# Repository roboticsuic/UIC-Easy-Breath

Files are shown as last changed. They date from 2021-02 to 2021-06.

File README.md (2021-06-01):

# Bioengineered breathing assistant for COVID-19

We are a group of four girls, form UIC, trying to mimic a mechanical ventilator for COVID-19 patients.
The overall mechanism consists in a 3D printed breathing machine structure connected to several electrical devices and all derived from an Arduino MKR 1000. There is a video of the all project in _EXTRA_ folder.

Here you will find both the 3D files in order to print the structure, and also the specific code to control it.
Remember that we are a group of undergraduates students, so this project is educational.

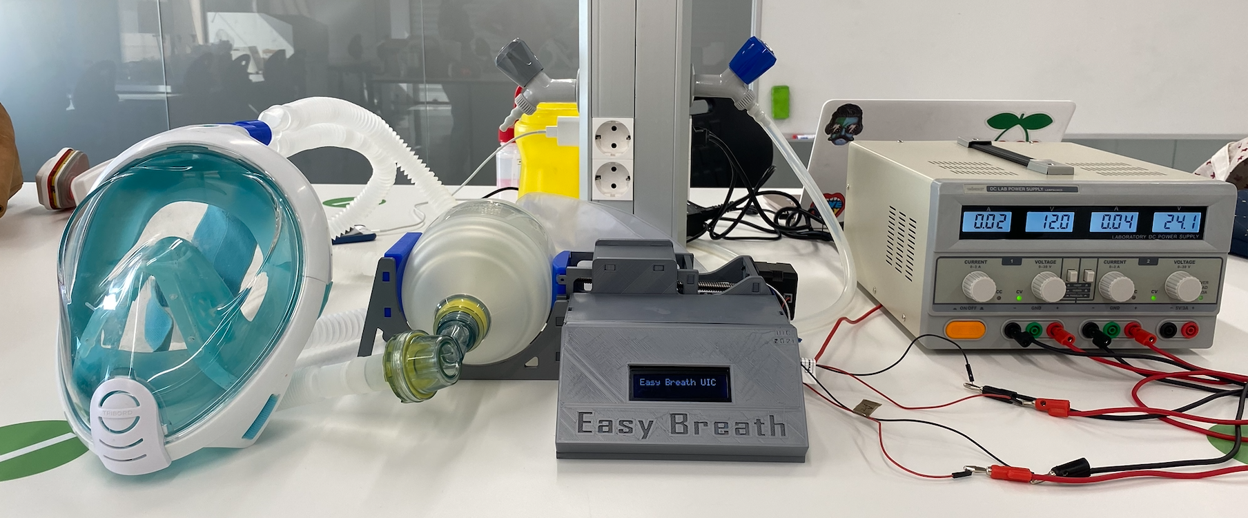
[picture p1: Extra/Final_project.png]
Final_project
 

**To contact us:**

Laura Olariaga: lolariaga@uic.es.

Ana Gatius: gatiusana@uic.es.

Èlia Vendrell: eliavendrell@uic.es.

Meritxell Clos: meritxell.clos@uic.es.

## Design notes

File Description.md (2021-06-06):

# UIC Easy Breath
## PROJECT: **Bioengineered breathing assistant for COVID-19**

At the end of 2019 a global pandemic changed our lives: we weren’t able to leave home, couldn’t hang out with friends… What is more, the medical services collapsed due to the big necessity of medical attention for COVID patients.

This project is based on the manufacture of a breathing assistant for COVID-19, a device designed to help those suffering severe breathing difficulties while affected by this virus. The aim of this project is to report how we created an electric device with the ability to provide sufficient oxygen to those patients.

The overall mechanism consists in a 3D printed breathing machine structure connected to several electrical devices and all derived from an Arduino MKR 1000.

The project is developed on the basis of a previous project that we found in Thingiverse (https://www.thingiverse.com/thing:4255247), where we got the breathing assistant model that we decided to print in 3D. In addition, we modified some of the previous pieces and also printed extra ones. For instance,  a display adapted box to place all the electronics of the mechanism

**_1. Objectives:_**

- Learn the basics of 3D printing and electronics in order to create a bioengineered breathing assistant for COVID-19.
- Create an accessible and fast 3D printed device in order to cover the urgent necessities during the COVID pandemic.
- Use motors and electronic devices in order to understand its functions.
- Be able to generate an Arduino code able to mimic the movements of the preexisting breathing machines, with the corresponding sensor.

**_2. Materials:_**

- For 3D printing: 
   - Blue, white and grey PLA.

- Softwares:
   - _SolidWorks_, to create and modify pieces.
   - _Ultimaker Cura_, to adjust setting parameters of the 3D printer.
   - _Meshmixer_, to detail and modify already created pieces.
   - _Prusa Slicer_, to add supports to the pieces before printing.

- For the electronics of the breathing assistant:
   - Arduino MKR1000.
   - Stepper motor NEMA 17.
   - Spindle Igus step 25.
   - Screw spindle Igus step 25.
   - Driver TB6600.
   - Screen SparkFun SerLCD.
   - Energy source 24V (5A).
   - Power regulator step down (24V to 10V).
   - Mechanical limit switch.
   - Pressure sensor (001PG2A5).
   - Buzzer.
   - Voltage conversor.
   - Voltage source (2 outcomes).

 - For the respiratory circuit:
   - Ambu respiratory bag.
   - Two corrugated tubes.
   - APL valve.
   - Peep valve.
   - Directionality valves.
   - Filter.

**_3. Definitions_:**

**MKR 1000 WIFI**:
- Price: 26.50€ 
- Size: Length 61.5mm Width 25mm.
- Weight: 32gr.
- Microcontroller: SAMD21 Cortex-MO + 32bit low power ARM MCU.
- Board Power Supply (USB/VIN): 5V.
- Supported Battery: Li-Po single cell, 3.7V, 700mAh minimum.
- Circuit Operating Voltage: 3.3V
- Digital I/O Pins: 8.
- PWM Pins: 12 (0,1,2,3,4,5,6,7,8,10,A3 -or 18 -, A4 -or 19).
- UART: 1.
- SPI: 1.
- 12C: 1.
- Analog Input Pins: 7 (ADC 8/10/12 bit).
- Analog Output Pins: 1(DAC 10 bit).
- External Interrupts: 8(0,1,4,5,6,7,8,A1 -or 16-, A2 - or 17).
- DC current per I/O Pin: 7mA.
- Flash Memory: 256KB.
- SRAM: 32KB.
- EEPROM: no.
- Clock Speed: 32.768kHz (RTC), 48MHz.
- LED_BUILTIN: 6.
- Full-speed USB Device and embedded Host.
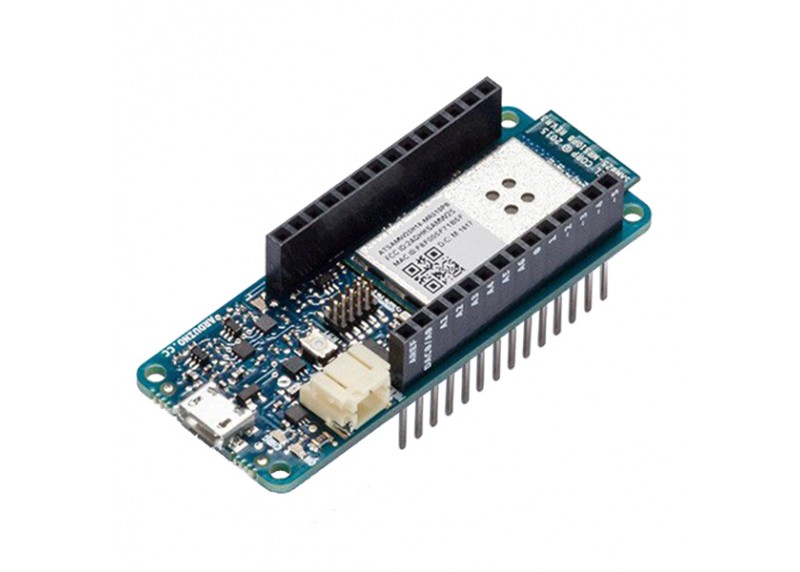
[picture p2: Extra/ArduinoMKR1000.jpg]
ArduinoMKR1000
 

**Pressure Sensor**:
- Price: 16,08€
- Manufactures: Honeywell.
- Model: 001PG2A5.
- Output Type: I2C, Address 0x28.
- Supply Voltage:  5.0 Vdc.
- Use: Medical Ventilators.
- Pressure Range: 0 psi to 1 psi.
- Pressure: Gauge.
- Weight: 4,250 g.
- Max. tension: 5,25V.
- Min. tension: 4,75V.
- Pinouts: Check table below.
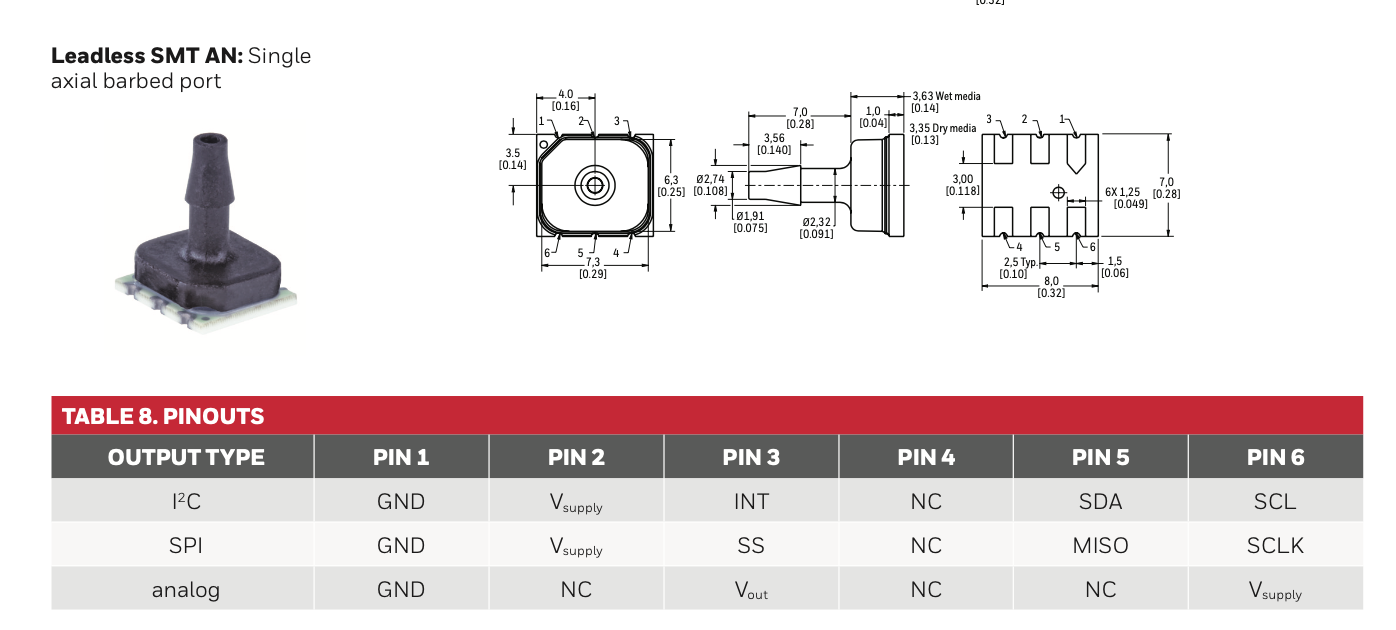
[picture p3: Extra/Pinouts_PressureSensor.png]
Pinouts_PressureSensor
- 

**Screen SparkFun SerLCD**
- Price: 16,37€.
- Dimensions: 16x2mm, RGB on Black Display.
- Manufactures: SparkFun.
- InPut Voltage: 3.3V.
- Weight: 2.2084 g.
- Connection: Qwiic.

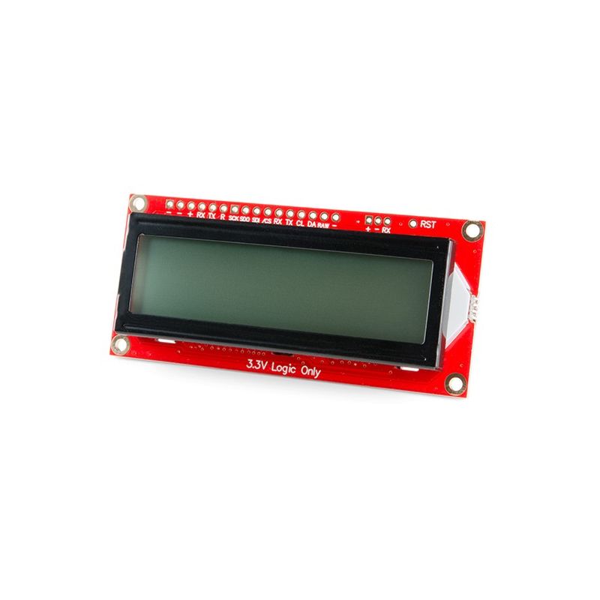
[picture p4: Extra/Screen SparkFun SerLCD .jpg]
Screen%20SparkFun%20SerLCD%20%20


**Stepper motor NEMA 17**
- Price: 21,66€.
- Size: 42.3x48mm, without including the axis.
- Weight: 350 g.
- Axis diameter: 5mm.
- Axis length: 25mm.
- Steps per turn: 200 (1.8º/step.
- Current: 1.2 Amps per winding.
- Voltage: 4V.
- Resistance: 3.3 Ohm per bobbin.
 
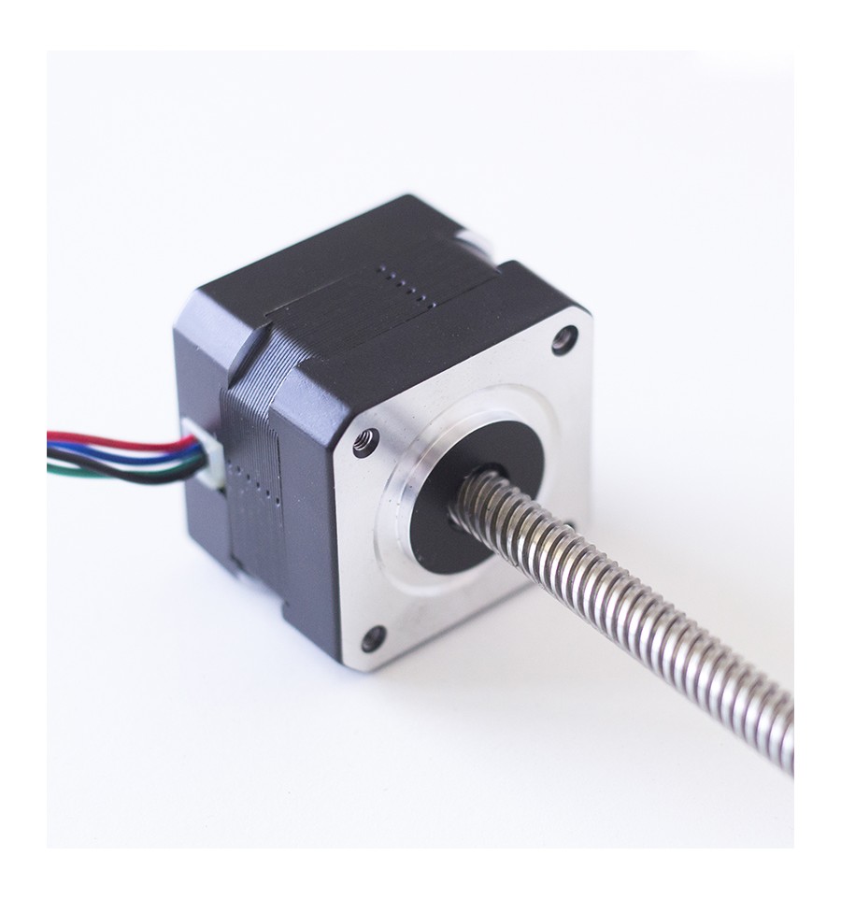
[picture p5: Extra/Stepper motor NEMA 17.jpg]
Stepper%20motor%20NEMA%2017


**Driver TB6600**
- Price: 18.90€.
- Input current: 0-5.0 A.
- Output current: 0.5 - 4A.
- Power: 160W
- Temperature: -10 to 45 degrees.
- Weight: 200g.
- Dimensions: 96x56x33mm.
- Connections: See picture above.

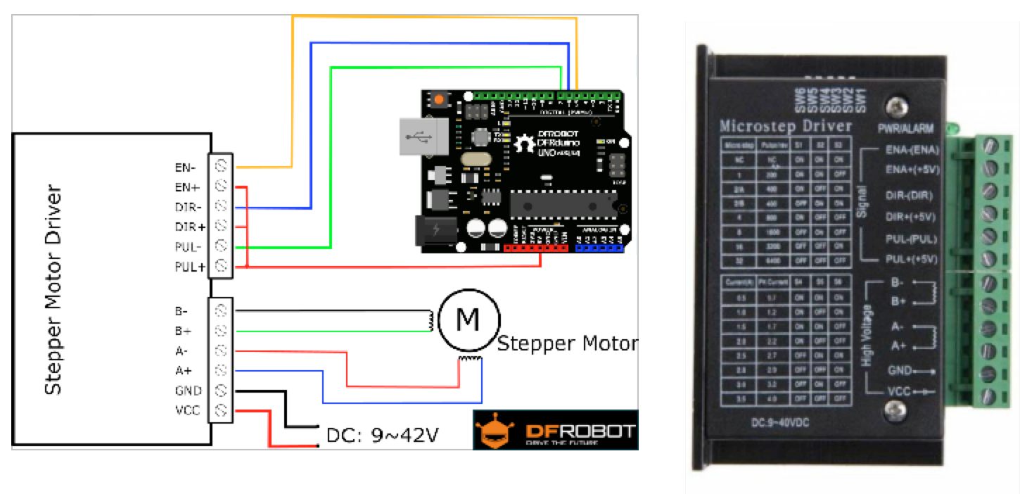
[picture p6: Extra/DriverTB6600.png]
DriverTB6600


**XL4015 DC Voltage Converter**
- Price: 3€.
- Input Voltage: 4.5V - 38V.
- OutPut Volatge: 1.25 - 36.5V
- OutPut power: 75W.
- Current Voltage: 4,5A.
- Temperature: -40 to 85 degrees.
- Operating frequency: 180kHz.
- Dimensions: 62x38x15 mm.
- Short circuit protection: Yes
- Functions: Step-down converter with overcurrent protection.
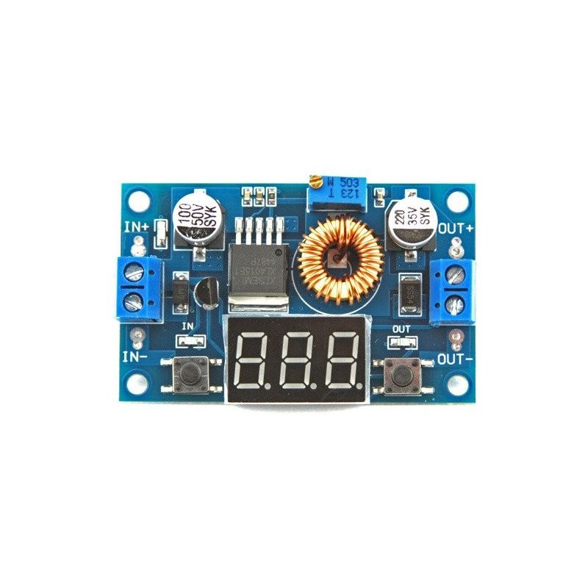
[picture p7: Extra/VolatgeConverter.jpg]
VolatgeConverter


**_4. Circuit_:**

Here you will find the proposed circuit with the corresponding connections:
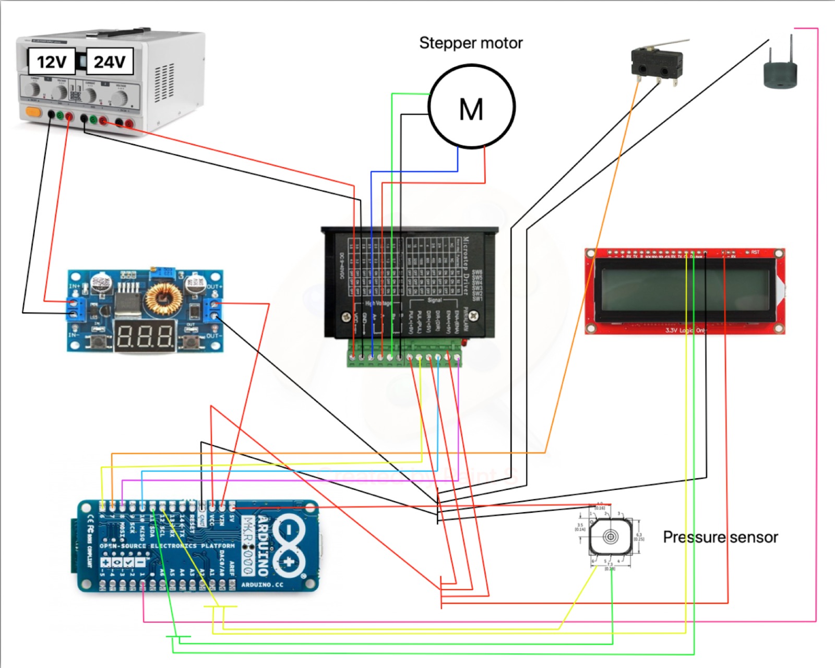
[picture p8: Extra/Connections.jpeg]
Connections


**Pressure sensor**

_See picture in definitions section._
- 3.3V corresponds to 5V
- SDA and SCL are connected to arduino
- The two remaining pins are not used

**XL4015 DC Voltage Converter**

_See picture in definitions section._ 
- IN+/- connected to voltage source 12V
- OUT+ connected to VIN arduino MK1000
- OUT- connected to GND arduino MK1000

**Driver TB6600 and Stepper motor NEMA 17**

_See picture in definitions section._   
- ENA- pin 8
- ENA+, DIR+, PULL+ → 3.3V 
- DIR- pin 10
- PULL- pin 6
- B- (black), B+ (green), A- (red), A+ (blue) → stepper motor
- GND, Vcc → voltage source 24V 

**Screen SparkFun SerLCD**
   
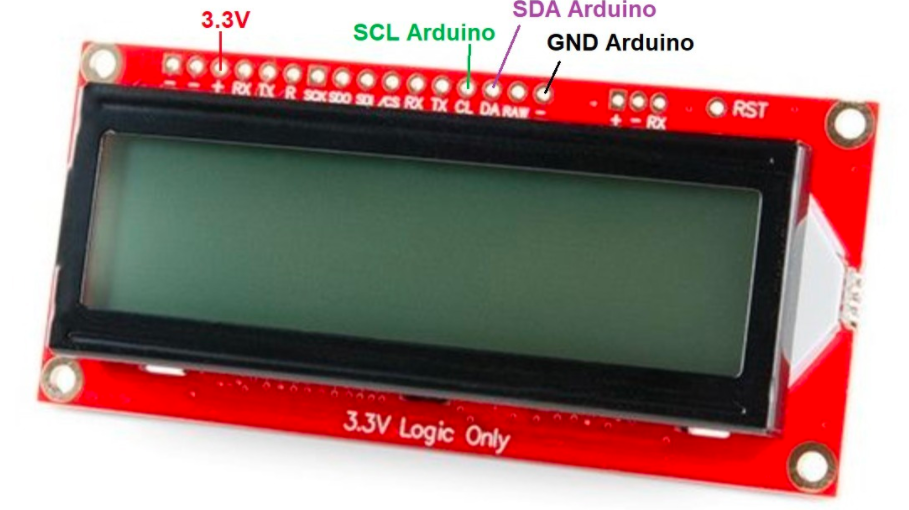
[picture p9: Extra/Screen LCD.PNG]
Screen%20LCD


**Buzzer** 
   
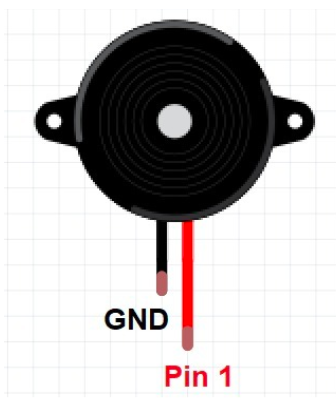
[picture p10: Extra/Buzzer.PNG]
Buzzer


**Limit Switch**
   
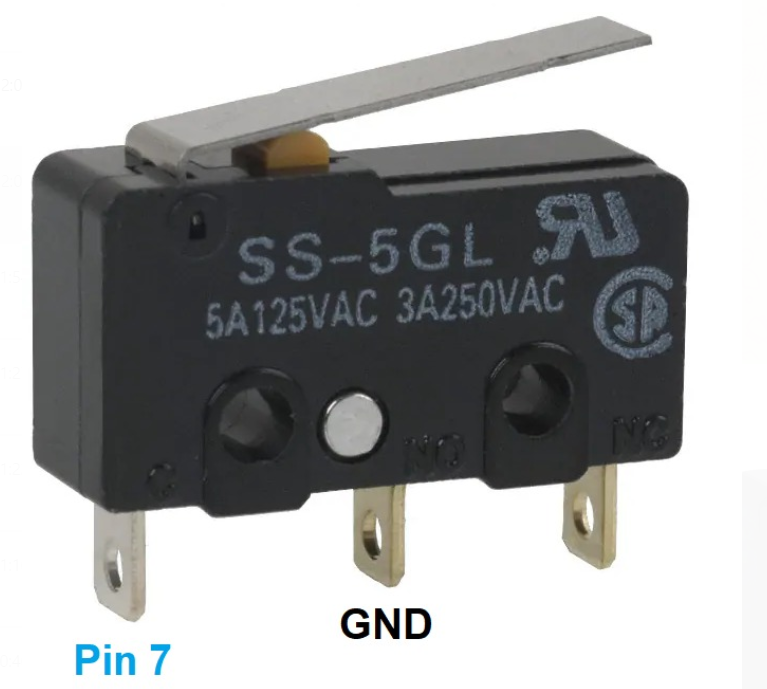
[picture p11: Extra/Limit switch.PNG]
Limit%20switch


_Notes:_
We have used common conexions for several components which end up in the same pin.
- A common conexion for SDA and SLA for the pressure sensor and the screen in arduino pins.
- OUT- from the voltage conversor is connected to GND arduino, while GND connections in the pressure sensor, buzzer, limit switch and screen are commonly connected to the first one.
- Vcc pin from arduino is commonly connected to ENA+, DIR+, PULL+ and 3.3V pin from screen.

**_5. Code_:**
   
Here you will find the main explanation of our code. The entire code is in the _CODE_ folder.

_Libraries:_  
   - Wire: Communicates with the IC2.
   - SerLCD: Communicates with the screen.
   - Honeywell_ABP: Communicates with the pressure sensor.

_Medical calculations:_
   - Used to modulate the respirator depending on the patient’s needs.

_Communications with Monitor Serie:_     
   - Serial.begin(9600)→ 9600ms are the velocity that the massage is send to the Monitor Serie.
   - Serial.setTimeout(100)→ 100ms are the waiting time to print in the screen.

_Define Inputs&Output:_
  - pinMode(finalcarrera, INPUT_PULLUP)→ Pullup as monitor the state of a switch.
  - Scl→ Is the system clock.
  - Sda→ Is the system data.

_Screen communications with the Monitor Serie:_
   - Used for:
      - Displacement
      - Breathing per minute (rpm)
         - Total breathing counting; as is an integer, its limit is 32 bits or 2.147.483.647 rpm.
      - Ratio inhalation/expiration 

_Calculations during process:_
   - Inhalation_
      - digitalWrite(dirNeg, HIGH)→ High as the movement is in X negative.
   - Expiration:
      - digitalWrite(dirNeg, LOW)→ Low as the movement is in X positive.
            
_Limit switch and Buzzer:_
   - Used for:
       - If low:
          - It will show an error, as the machine is obstructed and isn’t working.
          - When an error, the buzzer sounds.
       - If high:
          - Is for the expiration movements.
          - When the limit switch is high, it means that the motor has reach the maximal position, and it turns to the other direction (X negative)

_Pressure Sensor:_
   - Used for:
       - If no extra pressure: the sensor is working but without reporting the information on the screen.
       - If too much pressure: the sensor detects this increase. Without stopping the ventilator, there are some modifications:
          - The screen reports the number in cmH2O.
          - The buzzer sounds for 1 second.
    
_Reset:_
   - Used to reset the program when necessary, restarting it again at the introduction of new variables.

**_6. Softwares_:**

**SolidWorks**

 _SolidWorks_ is modeling a computer-aided design (CAD) program that allowed us to create the breath assistant's structure quickly and precisely. The whole structure is composed of 12 different pieces and all of them have to fit with each other, as this project doesn’t contain any screws or ties. However, this part didn’t require a lot of time as all the 12 pieces were previously created by another Catalan University (UPC). A maximum of five days were required for printing the whole structure. The final outcome was the following: 
 
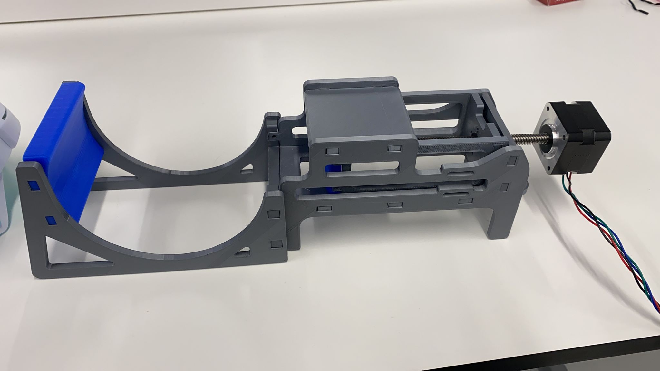
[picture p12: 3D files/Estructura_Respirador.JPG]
Estructura_Respirador
 

On the other hand, _SolidWorks_ was constantly used during our project due to the improvements that our group decided to do. To do that, we used the _SolidWorks_ program to create a new plane in the upper surface, and insert the corresponding text. The difficult part was to figure out which direction was the perfect one, due to the face-mask connector would be seen in the opposite direction. On the other hand, we also incorporare our logo in the frontal part of the box and our surnames in the lateral part of it.
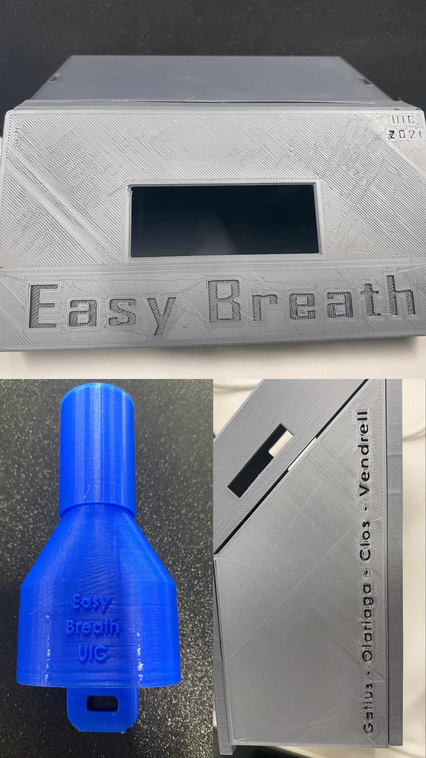
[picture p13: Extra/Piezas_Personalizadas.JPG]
Piezas_Personalizadas


Secondly, this program was also used to create the needed structure to connect the breath assistant with the medical tubs. To do it, we measured the most external part of both devices with a vernier caliper, and with such dimensions, we created the connector.
Thirdly, we decided that one of the initial 12 structures had to have all its surface with PLA. To do that, we create a new plan over the created, and we extrude it. 

Finally, we wanted to create a box to keep all the tools together and well-organized. But this box couldn’t be as the typical ones, but with a certain orientation in one of the faces as we also have a screen to fit inside of it. Therefore, the box had to be composed of different parts. First, we had to modify a preexisting project piece so the box could be attached to the breath machine. Secondly, the back part was created and also the laterals. Finally, the screen face  was designed with all the modifications needed to be able to use all buttons. As can be seen in the image below, all parts have rectangle holes or rectangular extrusions so they can be ansamble together and form the desired box.
In order to know if the box was designed properly, we assembled all the new pieces with Solid works, and the result is the following image.  
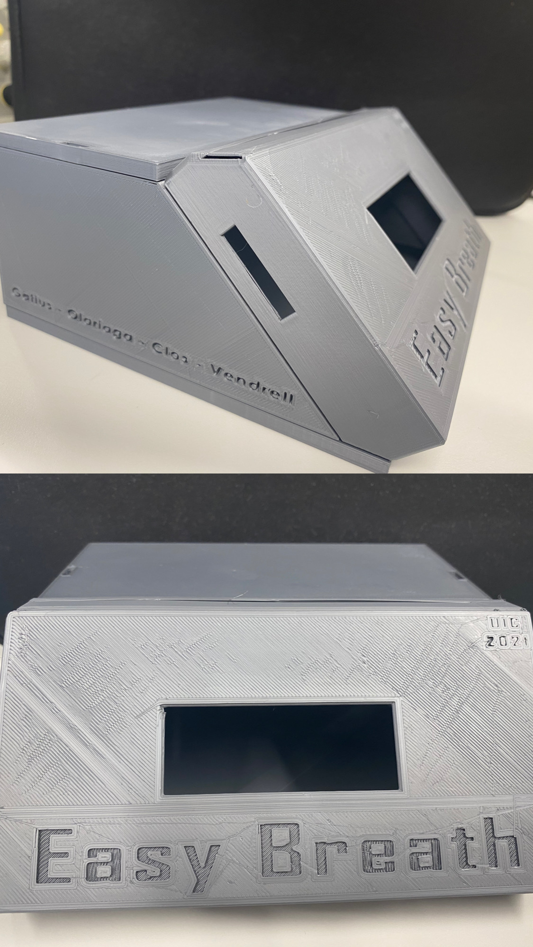
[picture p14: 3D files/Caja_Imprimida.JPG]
Caja_Imprimida


**Meshmixer**

_Meshmixer_ is a free software able to modify files in order to work with triangle meshes. We used it with the purpose of decreasing the adaptor’s resolution. This was due to the need to modify the structure to connect the tubes of the vent system. Moreover, we delete the preexisting letters on its surface to put on our own.

**Ultimaker Cura**

_Ultimaker Cura_ is a cutting software, which converts 3D models into G-code files, which will provide the 3D printer with all the necessary instructions for printing. It converts files in STL format to physical parts. All figures have been converted with Ultimaker Cura before printing. We adapt the printing parameters to improve the PLA printing.    

**Prusa Slicer**

_Prusa Slicer_, is a cutting software, which converts 3D models into G-code files, which will provide the 3D printer with all the necessary instructions for printing. We also used this software to print the adaptor but with the correct support in order to be printed accurately. See picture below.

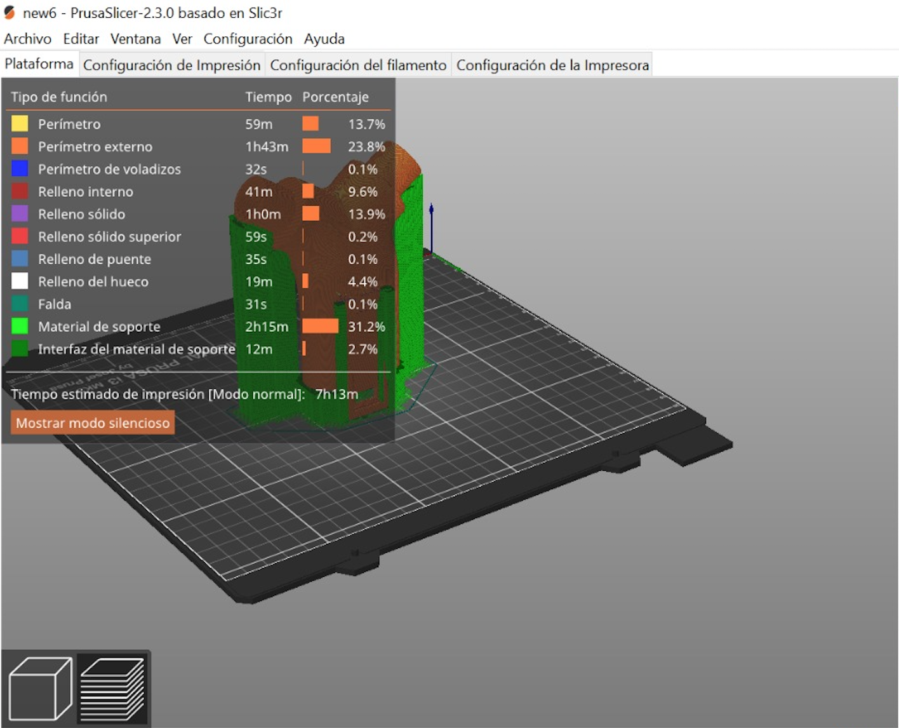
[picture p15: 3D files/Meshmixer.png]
Meshmixer


**_7. Conclusions_:**

Once our final project is done, we can conclude the following statemnts:

The aim of the project was to create a mechanical ventilator that worked automatically and was able to surpass common errors without the help of a medical assistant. The structural parts were printed with a MK3 PRUSA 3D printer with PLA in blue and grey colors. The box that holds all the electronics is composed of five parts that bind together by holes and extrusions, has a hole for the cables to pass, and has the Easy Breath logo in the front. The Arduino used was the MKR1000 model that combines the switch, sensor pressure, I2C screen, driver, buzzer, voltage converter, and stepper motor. The whole structure is connected to a 24V and 12V power supply. Errors that the program described can solve include: the detection of an increase of pressure of over 10 cmH2O that it showed in the screen visually and by a sound by the buzzer, and the detection of an early click of the switch button before it is necessary, the buzzer will also make a sound.

The project holds all the objectives proposed from the beginning, solving other issues found during the process being so; the mechanical ventilator can be printed with a conventional printer machine, Arduino is a proper device to control heavy files and structured document helps to improve existents projects. The last one being the most important one, it is essential for a public finished project to show and be well documented having not only the datasheet but also the exact device models. As so, we have described and attached all the files we have used so the project can be reproduced step by step.

As for future changes and improvements, a reset function can be included in the code. The reset function is useful in extreme cases when an external object gets attached to the device, for instance. If a cable or object gets stuck in the route of the stepper motor movement, there is a need of restarting the code without disconnecting the device. In the project, this approach was solved by showing an error message in the screen or showing the pressure, as well as a warning buzzer, and continuing the loop without stopping. Another alternative to polishing the project is to add a more complex screen that has buttons to select or is tactile, this is so a laptop is no needed.

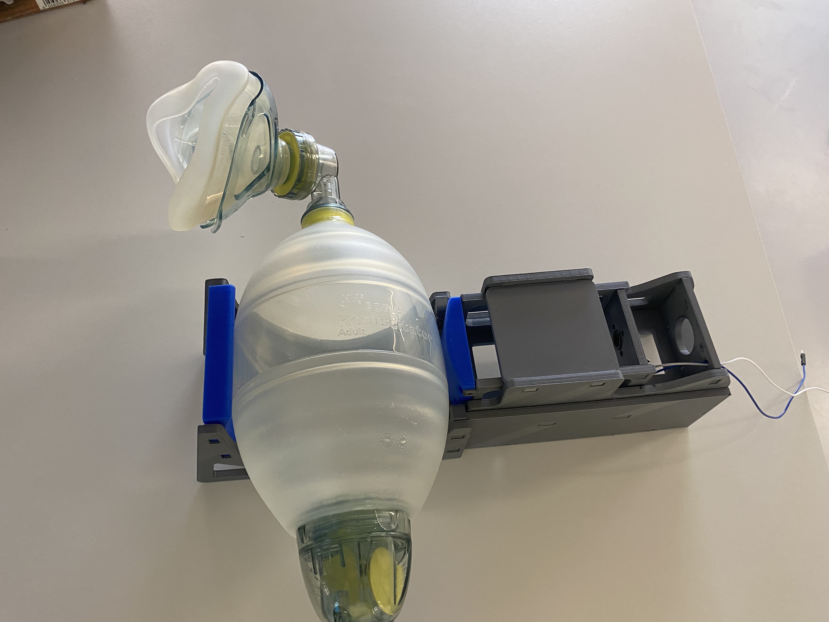
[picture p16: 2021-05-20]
Extra/Structure.JPG

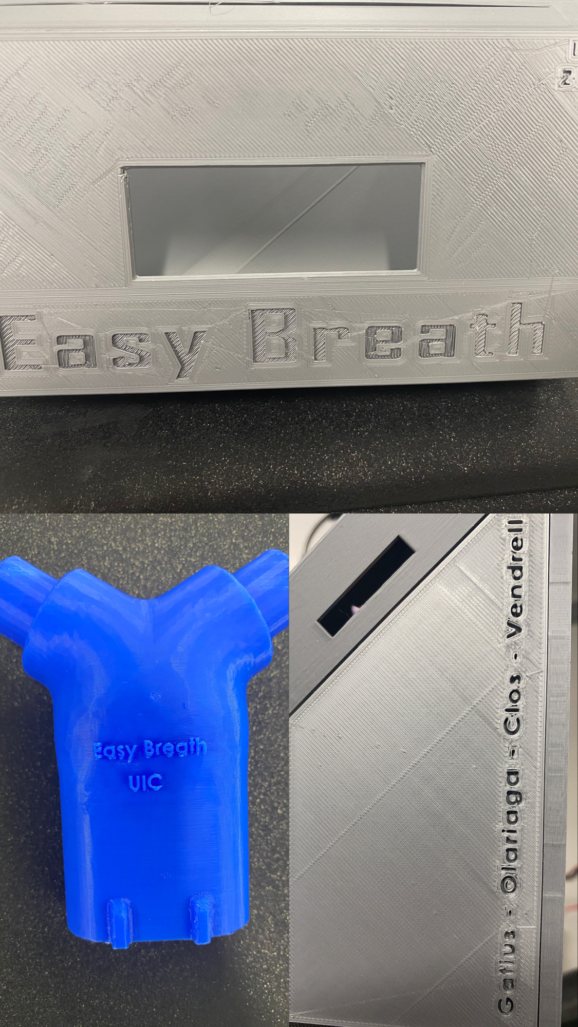
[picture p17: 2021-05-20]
3D files/Piezas_Personalizadas.JPG

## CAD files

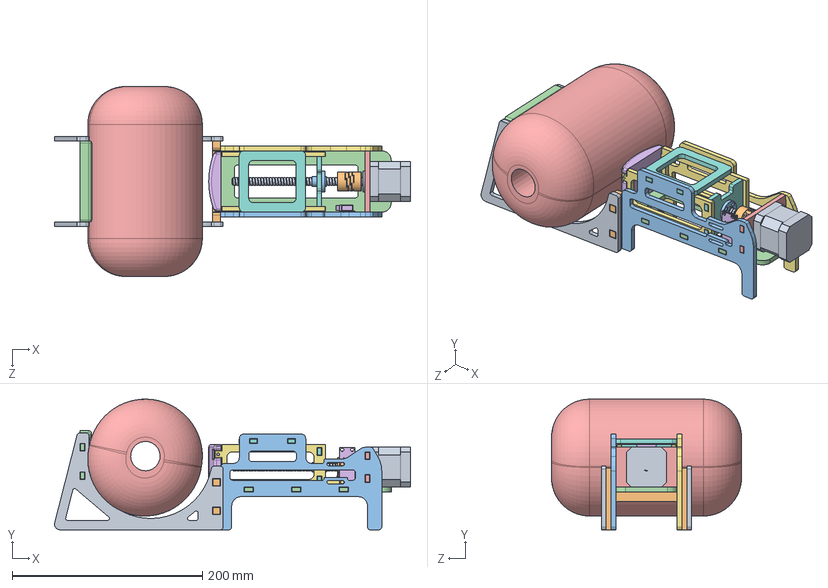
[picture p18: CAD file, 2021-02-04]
3D files/Ensamblaje.SLDASM
374.7 x 137.6 x 200.0 mm
V3-1 x 2
V3-2
V3-4
V3-5
V3-6
V3-7
V3-8 x 2
V3-9
Husillo v3-nema 17
Acople Flexible
LeadScrew-Nut
V3-3
Bolsa respiradero
Endstop
V3-4 - copia
V3-10

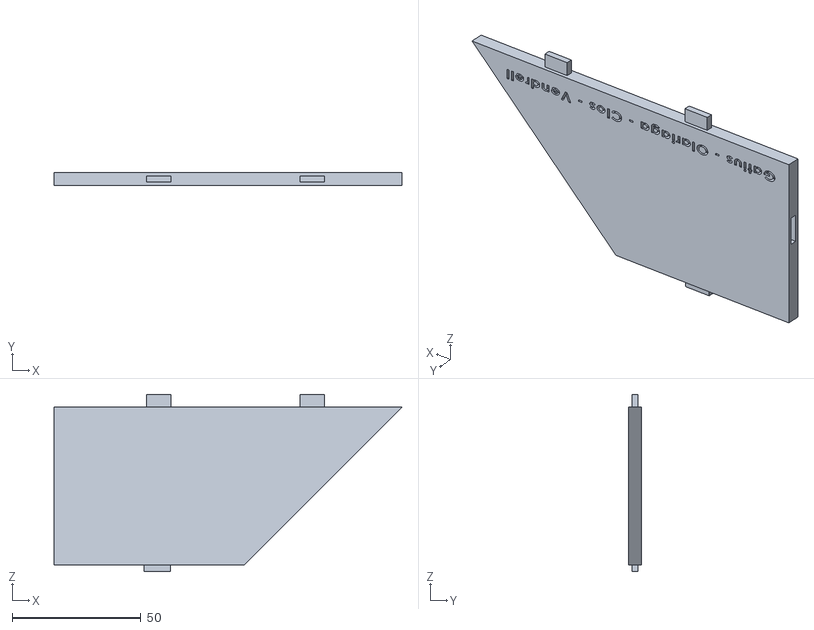
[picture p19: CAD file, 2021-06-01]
3D files/.STL/Lateral_2 caja.STL
135.0 x 5.00 x 68.8

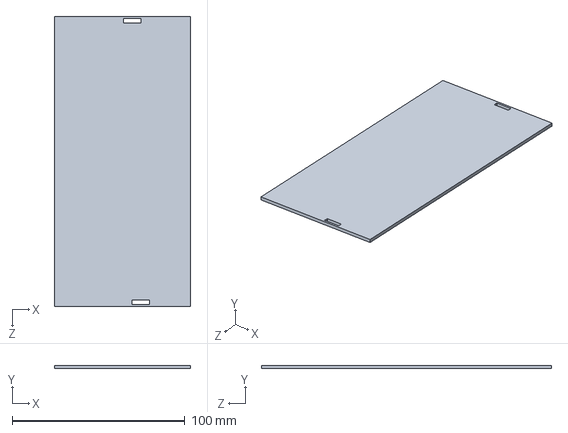
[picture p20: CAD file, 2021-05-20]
3D files/Tapa_Caja.SLDPRT
78.7 x 2.00 x 168.0 mm

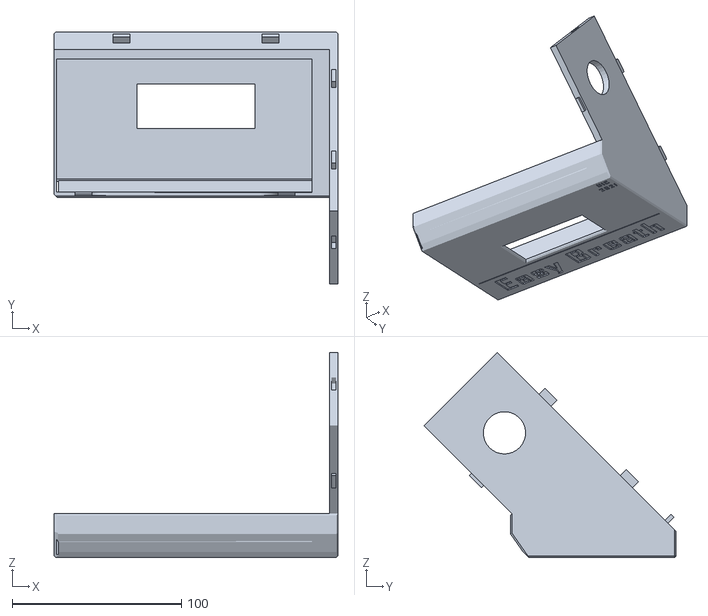
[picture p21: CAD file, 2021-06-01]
3D files/.STL/Pantalla_Lateral1 caja.STL
168.0 x 149.1 x 121.5

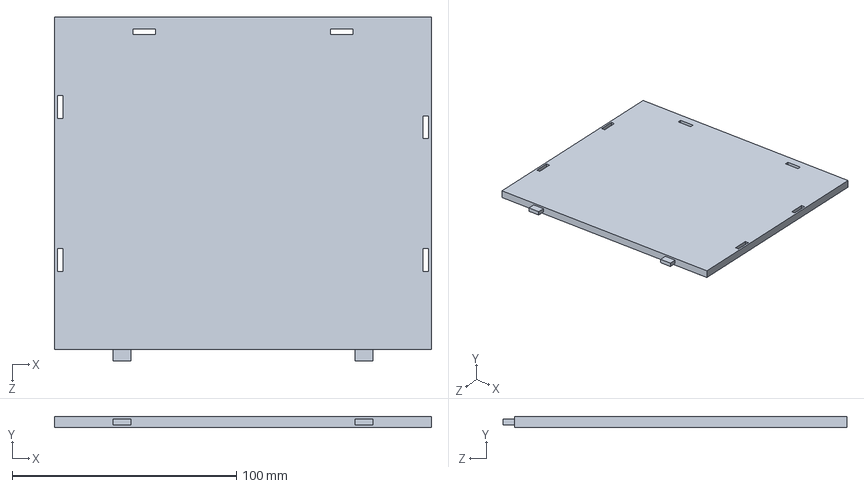
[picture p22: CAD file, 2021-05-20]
3D files/Suelo_Caja.SLDPRT
168.0 x 5.00 x 153.1 mm

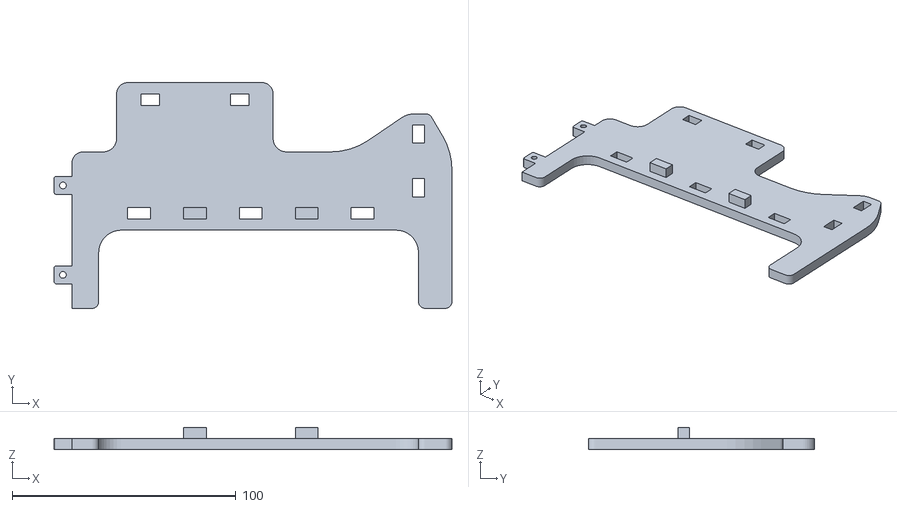
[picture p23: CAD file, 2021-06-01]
3D files/.STL/V4-2_Editada.STL
178.0 x 101.0 x 10.0

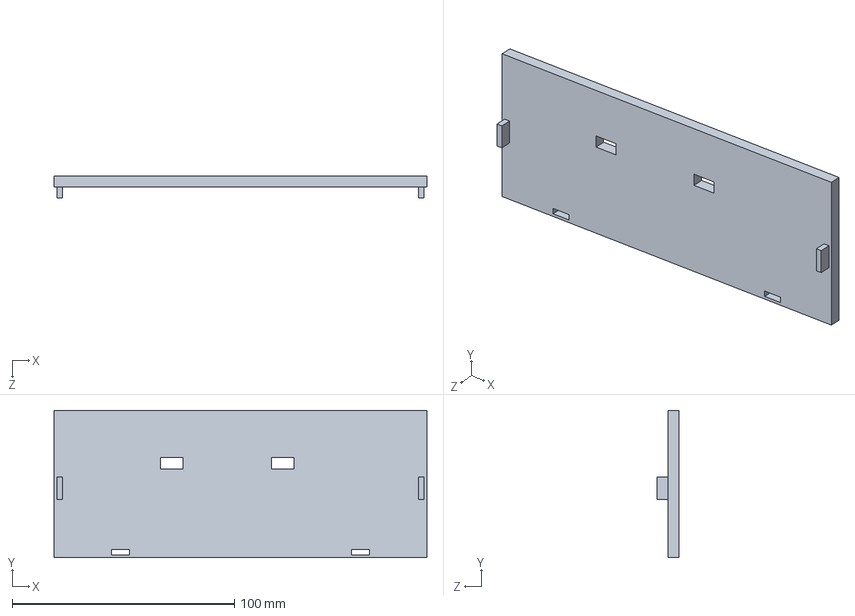
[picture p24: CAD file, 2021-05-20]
3D files/Trasero_Caja.SLDPRT
168.0 x 66.3 x 10.0 mm

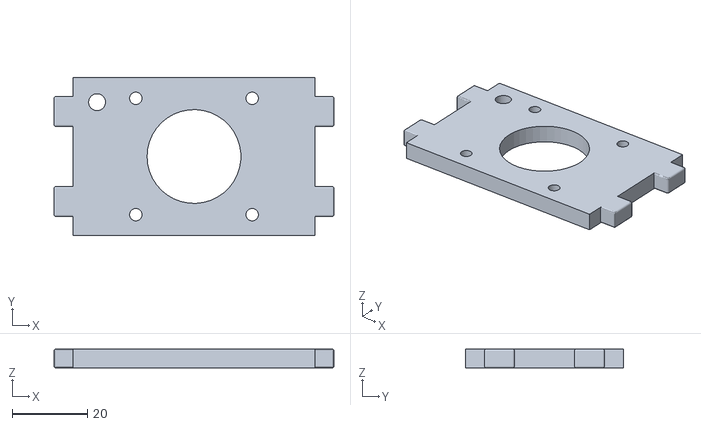
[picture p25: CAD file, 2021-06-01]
3D files/.STL/V6_Editada.STL
74.6 x 42.0 x 5.00

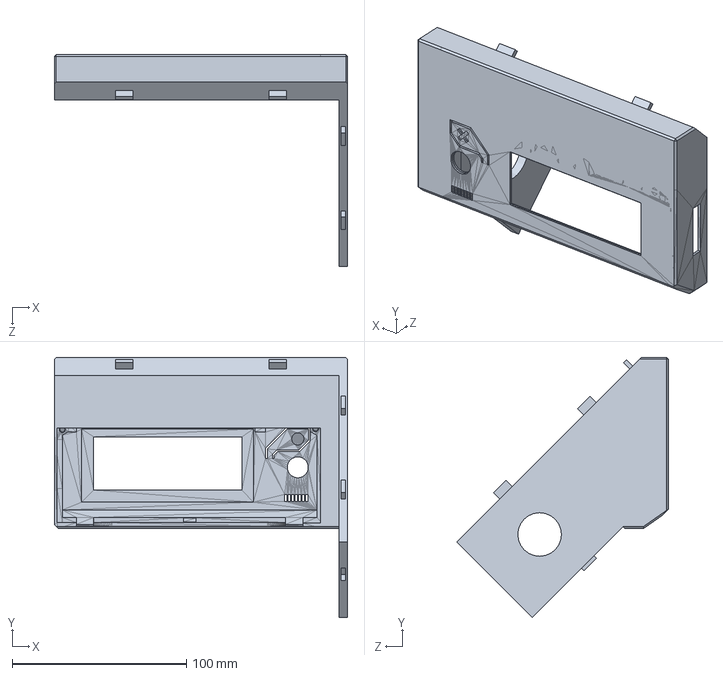
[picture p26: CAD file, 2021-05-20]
3D files/Pantalla_Caja.SLDPRT
168.0 x 149.1 x 121.5 mm

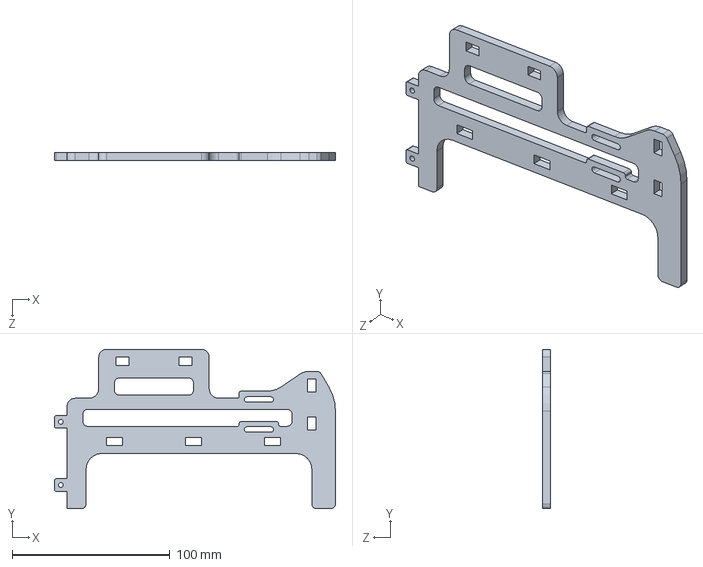
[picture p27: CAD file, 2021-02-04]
3D files/V4-2.SLDPRT
178.0 x 101.0 x 5.00 mm

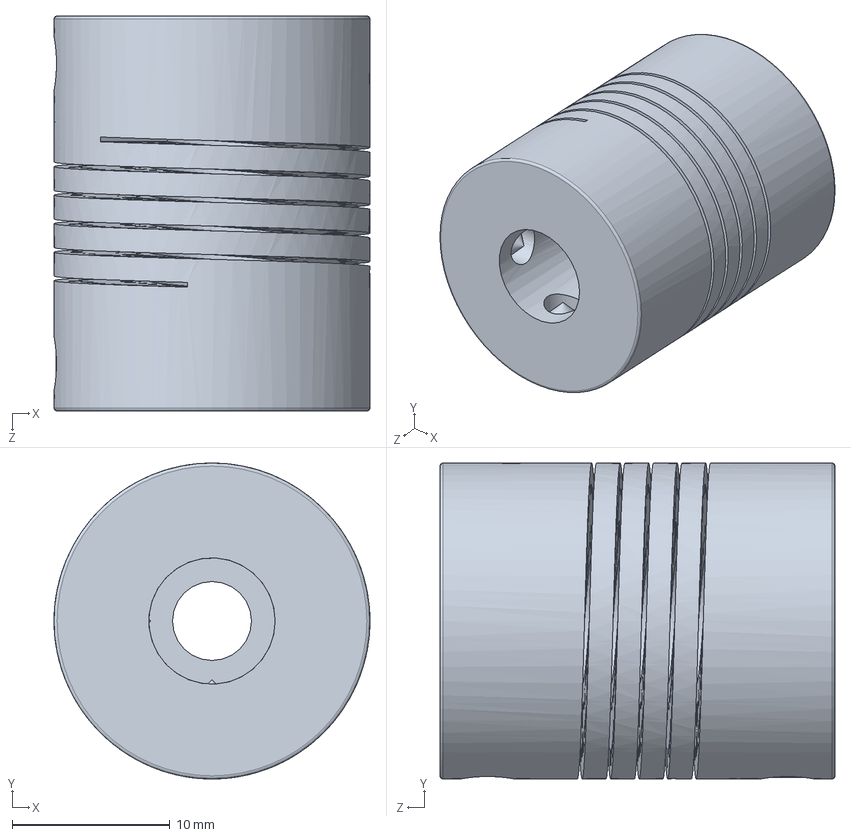
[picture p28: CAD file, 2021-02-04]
3D files/Acople Flexible.SLDPRT
20.0 x 20.0 x 25.0 mm

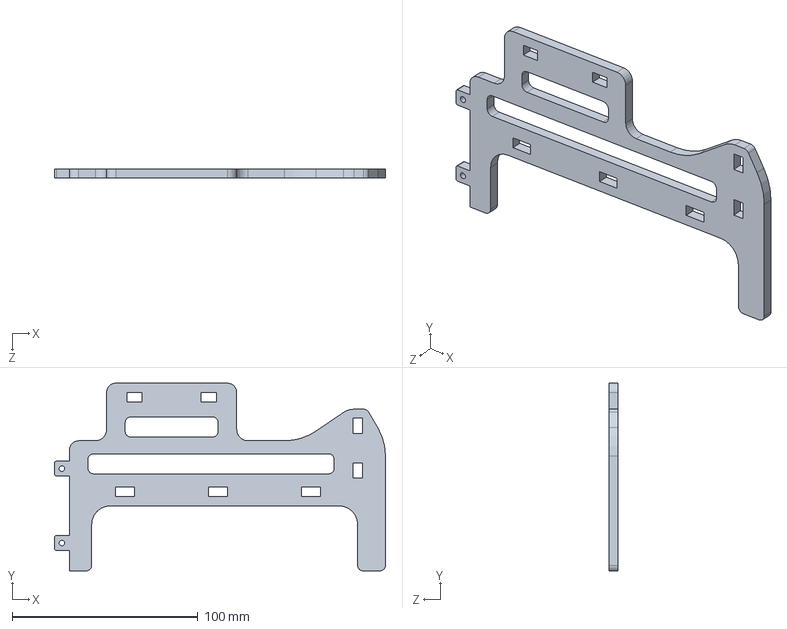
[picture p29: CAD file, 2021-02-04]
3D files/V4-1.SLDPRT
178.0 x 101.0 x 5.00 mm

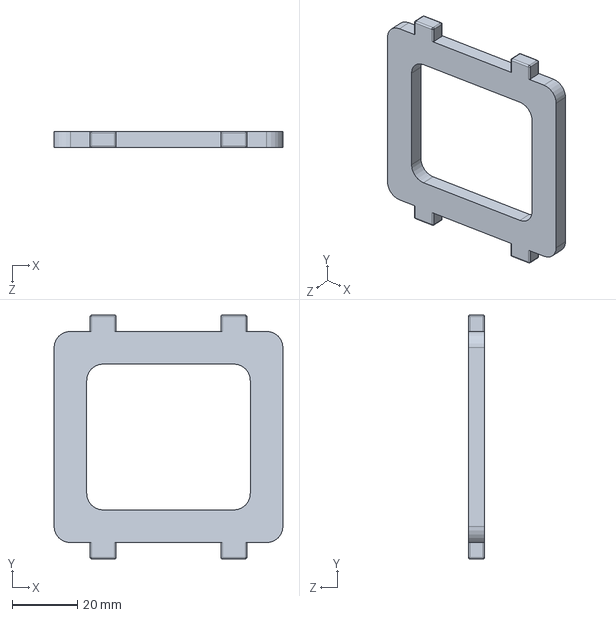
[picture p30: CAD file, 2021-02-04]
3D files/V10.SLDPRT
70.0 x 74.6 x 5.00 mm

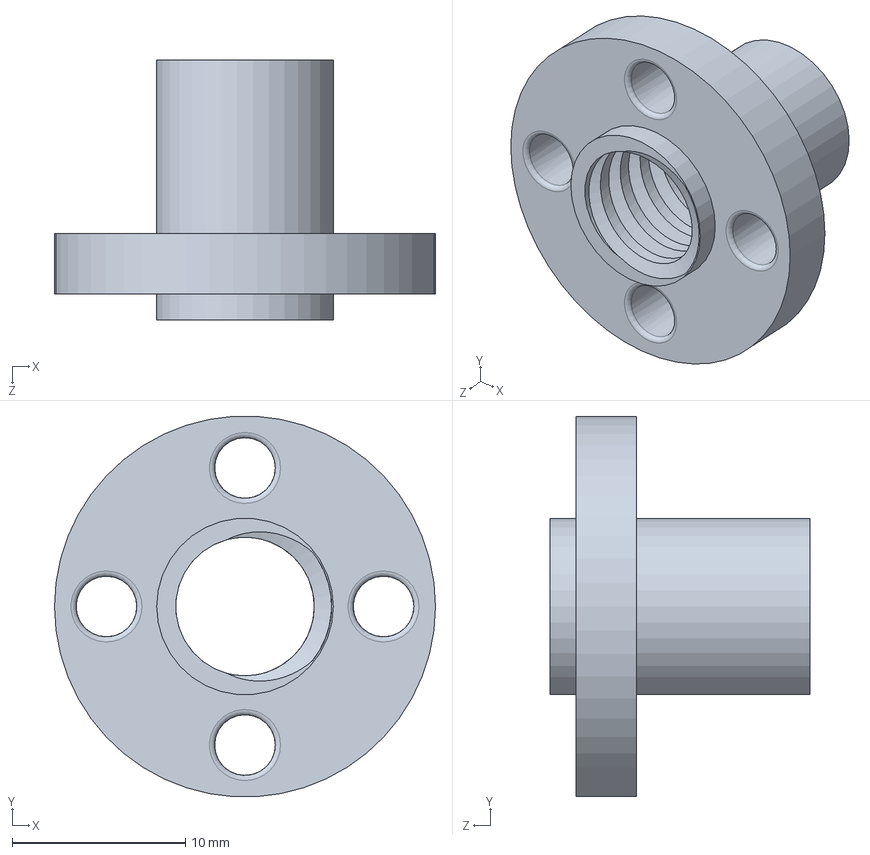
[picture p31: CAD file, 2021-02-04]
3D files/LeadScrew-Nut.SLDPRT
22.0 x 22.0 x 15.0 mm

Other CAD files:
3D files/.STL/Lateral-Trasero caja.STL
3D files/V6.SLDPRT
3D files/V5.SLDPRT
3D files/V8.SLDPRT
3D files/.STL/Suelo caja.STL
3D files/.STL/Tapa caja.STL
3D files/.STL/V1.STL
3D files/.STL/V10.STL
3D files/.STL/V2.STL
3D files/.STL/V3.STL
3D files/.STL/V4-1.STL
3D files/.STL/V4-2.STL
3D files/.STL/V5.STL
3D files/.STL/V6.STL
3D files/.STL/V7.STL
3D files/.STL/V8.STL
3D files/.STL/V9.STL
3D files/V1.SLDPRT
3D files/V2.SLDPRT
3D files/V3.SLDPRT
3D files/V7.SLDPRT
3D files/V9.SLDPRT

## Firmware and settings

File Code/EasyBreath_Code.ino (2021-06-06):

#include <Wire.h>//library that communicates with the IC2
#include <SerLCD.h> //library that communicates with the SCREEN
SerLCD lcd; // Communicates the screen with the IC2
#include <Honeywell_ABP.h>//library of the PRESSURE SENSOR
// refer to datasheet for parameters

Honeywell_ABP abp( //parameters of the sensor
  0x28,   // I2C address
  0,      // minimum pressure
  1,      // maximum pressure
  "psi"   // pressure unit (pounds per square inch)
);

//defines pins
const int stepPin = 6;  //PULSE- 
const int finalcarrera = 7; //Electric limit switch
const int buzzer = 1; //Buzzer
const int enaNeg= 8; //ENA- (off line control enable-)
const int dirNeg= 10; //DIRECTION-
int Scl=12; //includes sensor and screen. Clock
int Sda=11; //includes sensor and screen. Data
int sensorValue=0; //value 0 of sensor at the beginning
int presion=0; //value 0 of pressure at the beginning


//Variables
const int stepsxrev = 6400; //steps of motor revolution 
const int mmxrev= 8; //displacement milimeters of the spindle per revolution 

int stepdelayInsp = 0;    //microsegundos entre paso y paso - Inspiración
int stepdelayExp = 0;     //microsegundos entre paso y paso - Expiración
int stepdelay = 0;        //microsegundos entre paso y paso - General

int targetsteps = 0;         // pasos necesarios para llegar al punto marcado

int t1 = 500;               //tiempo de espera Inspiración (milisegundos)
int t2 = 500;               //tiempo de espera Expiración (milisegundos)

int disp = 0 ;              //desplazamiento
int RPM = 0;                //Respiraciones por minuto
int ratio = 2 ;             //Ratio inspiracion/expiracion 
int ratioDen = 2 ;          //Para el calculo Ratio inspiracion/expiracion
int tCiclo = 0;             //Tiempo de ciclo
int tInsp = 0;              //Tiempo inspiración
int tExp = 0;               //Tiempo expiración
int restart;

int i = 0;                  //contar resp min
unsigned long start, finish, elapsed, over;    //Para calcular el tiempo
float h, m, s;


void setup() {
  //Iniciamos comunicación con el puerto serie
  Serial.begin(9600); //
  Serial.setTimeout(100);

  //Sets the pins as Outputs
  pinMode(stepPin,OUTPUT);
  pinMode(dirNeg,OUTPUT);
  pinMode(finalcarrera,INPUT_PULLUP);
  pinMode(buzzer,OUTPUT);
  pinMode(enaNeg, OUTPUT);

  pinMode(Scl,INPUT);
  pinMode(Sda,INPUT);
  
  Wire.begin(); // open I2C communication

  lcd.begin(Wire); //Set up the LCD for I2C communication

  lcd.setBacklight(255, 255, 255); //Set backlight to bright white
  lcd.setContrast(5); //Set contrast. Lower to 0 for higher contrast.


   //Leemos valor de desplazamiento+
   lcd.clear(); //Clear the display - this moves the cursor to home position as well
  lcd.print("DESPLAZAMIENTO  mm (50 - 80):");
  while (!Serial.available() > 0);   // Esperamos valor
   {
      disp = Serial.readString().toInt();
    
      lcd.clear();
      lcd.print("DESPLAZAMIENTO  SELEC: ");
      lcd.print(disp);
      lcd.print(" ");
    }
 delay(3000);

 //Leemos valor respiraciones minuto
 lcd.clear(); //Clear the display - this moves the cursor to home position as well
 lcd.print("RESPIRACIONES MINUTO (10 - 20):");
 while (!Serial.available() > 0);   // Esperamos valor
  {
      RPM = Serial.readString().toInt();
      
      lcd.clear();
      lcd.print("RESPIRACIONES   SELEC: ");
      lcd.print(RPM);
      lcd.print(" ");
    }
delay(3000);

   //Leemos valor Ratio I/E
 lcd.clear(); //Clear the display - this moves the cursor to home position as well
 lcd.print("RATIO I/E       (1, 2, 3, 4):");
 while (!Serial.available() > 0);   // Esperamos valor
  {
      ratio = Serial.readString().toInt();
      
      lcd.clear();
      lcd.print("RATIO I/E       SELEC: 1:");
      lcd.print(ratio);
      lcd.print(" ");
    }
delay(3000);


    //Calculos iniciales
    lcd.clear();
    tCiclo = (60000/RPM) ;
    lcd.print("Tiempo de ciclo: ");
    lcd.print(tCiclo);
    delay(3000);
    
    lcd.clear();
    ratioDen = 1+ratio;
    tInsp = (tCiclo/ratioDen) ;
    lcd.print("Tiempo de Inspiracion: ");
    lcd.println(tInsp);
    delay(3000);
    
    lcd.clear();
    tExp = ((tCiclo*ratio)/ratioDen) ;
    lcd.print("Tiempo de Expiracion: ");
    lcd.println(tExp);
    delay(3000);
 
    lcd.clear();
    targetsteps = (disp)*(stepsxrev/mmxrev);   //Pasos para el desplazamiento
    lcd.print("Pasos necesarios: ");
    lcd.println(targetsteps);
    delay(3000);
    //Si queremos velocidades diferentes de Inspiración y Expiración
    //stepdelayInsp = (((float)tInsp*1000)/((float)targetsteps*2)) ;   //microsegundos entre paso y paso - Inspiración
    //Serial.println(stepdelayInsp);
    //stepdelayExp = (((float)tExp*1000)/((float)targetsteps*2)) ;     //microsegundos entre paso y paso - Expriración
    //Serial.println(stepdelayExp);

    //Misma velocidad Inspiración/Expiración
    lcd.clear();
    stepdelay = (((float)tInsp*1000)/((float)targetsteps*2)) ;   //microsegundos entre paso y paso - Insp y Exp
    lcd.print("Delay pasos: ");
    lcd.println(stepdelay);
    stepdelayInsp = stepdelay;
    stepdelayExp = stepdelay;
    delay(3000);
} 
  
void loop() {
  
    //test para contar el tiempo
    i= i + 1; //int limit = 32 bits = 2.147.483.647
    lcd.clear();
    lcd.print("Respiracion num: ");
    lcd.println(i);
    delay(3000);

         //INSPIRACIÓN
     lcd.clear();
     lcd.print("INHALACION ");
     
     for(int i = 0; i < targetsteps; i++) { //loop de movimiento de 0 a pasos necesairos
        digitalWrite(dirNeg,HIGH); //inicia movimiento en sentido X negativo
        digitalWrite(enaNeg,HIGH);
        digitalWrite(stepPin,HIGH);
        delayMicroseconds(stepdelayInsp);
        digitalWrite(stepPin,LOW);
        delayMicroseconds(stepdelayInsp);        
      }
      

      //Comprobamos que el final de carrera no está pulsado -> LOW significa que está pulsado 
      while (digitalRead(finalcarrera)==LOW)  {
        lcd.println(); 
        lcd.println();
        lcd.clear();
        lcd.println("ERROR!!!");                //Crear alarma que pare la máquina
        lcd.println();
        tone(buzzer, 1200); // Send 1KHz sound signal...
        delay(500);        // ...for 1 sec
        noTone(buzzer);     // Stop sound...
        delay(500);        // ...for 1sec
      }
      
      //delay (t1);     //Espera -> modificar pasos

      //EXPIRACIÓN - Hasta final de carrera
      lcd.clear();
      lcd.print(" ->  EXHALACION ");
           
     while(digitalRead(finalcarrera)==HIGH) { //loop de movimiento de 0 a pasos necesairos
        digitalWrite(dirNeg,LOW); //inicia movimiento en sentido X positivo
        digitalWrite(enaNeg,HIGH);
        digitalWrite(stepPin,HIGH);
        delayMicroseconds(stepdelayExp);
        digitalWrite(stepPin,LOW);
        delayMicroseconds(stepdelayExp);        
      }
     
     presion=abp.pressure()* 70,308890742557;
        // update sensor reading
        abp.update();
      
        if (presion>10){
          // print sensor reading via serial
          lcd.clear();
          lcd.print("Presion PEEP:   ");
          lcd.print(presion);
          lcd.print(" ");
          lcd.println("cmH2O");
          tone(buzzer, 1200); // Send 1KHz sound signal...
          delay(500);        // ...for 1 sec
          noTone(buzzer);     // Stop sound...
          delay(500);        // ...for 1sec
        }
        


lcd.clear();

  while (!Serial.available() > 0);   // Esperamos 'Reset'
   {
       // read the incoming string:
    String incomingString = Serial.readStringUntil('\n');

    // prints the received data
    Serial.print("Ventilator is going to restart, as received ");//...Reset
    Serial.println(incomingString);
    lcd.clear();
    lcd.println("Ventilator is going to restart");                //Crea variable que pare la máquina y la reinicie.
    lcd.println();
  }

 
 reiniciar(); // Llamámos a la función 'reiniciar'.
 lcd.clear();
 lcd.println("Introducir nuevos parametros");
 delay(500);        // ...for 1sec
  
} // Cierra el loop

void reiniciar()  // Creamos una nueva función para reiniciar el equipo cuando sea necesario.
  {
    lcd.clear(); //Clear the display - this moves the cursor to home position as well
      lcd.print("DESPLAZAMIENTO  mm (50 - 80):");
      while (!Serial.available() > 0);   // Esperamos valor
       {
          disp = Serial.readString().toInt();
        
          lcd.clear();
          lcd.print("DESPLAZAMIENTO  SELEC: ");
          lcd.print(disp);
          lcd.print(" ");
        {
     delay(3000);
    
     //Leemos valor respiraciones minuto
     lcd.clear(); //Clear the display - this moves the cursor to home position as well
     lcd.print("RESPIRACIONES MINUTO (10 - 20):");
     while (!Serial.available() > 0);   // Esperamos valor
      {
          RPM = Serial.readString().toInt();
          
          lcd.clear();
          lcd.print("RESPIRACIONES   SELEC: ");
          lcd.print(RPM);
          lcd.print(" ");
        }
    delay(3000);
    
 
lcd.clear();

       //Leemos valor Ratio I/E
     lcd.clear(); //Clear the display - this moves the cursor to home position as well
     lcd.print("RATIO I/E       (1, 2, 3, 4):");
     while (!Serial.available() > 0);   // Esperamos valor
      {
          ratio = Serial.readString().toInt();
          
          lcd.clear();
          lcd.print("RATIO I/E       SELEC: 1:");
          lcd.print(ratio);
          lcd.print(" ");
        }
    delay(3000);
      
    }

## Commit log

2021-06-01 Create .STL documents
2021-06-01 Create .STL files
